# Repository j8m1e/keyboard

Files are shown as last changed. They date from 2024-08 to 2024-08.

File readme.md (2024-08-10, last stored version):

Quefrency
=========

A split 60% staggered keyboard made and sold by Keebio. [More info at Keebio](https://keeb.io).

Keyboard Maintainer: [Bakingpy/nooges](https://github.com/nooges)  
Hardware Supported: Pro Micro  
Hardware Availability: [Keebio](https://keeb.io/)  

Make example for this keyboard (after setting up your build environment):

    make keebio/quefrency/rev1:default

Example of flashing this keyboard:

    make keebio/quefrency/rev1:default:avrdude

Handedness detection is already hardwired onto the PCB, so no need to deal with `EE_HANDS` or flashing .eep files.

See [build environment setup](https://docs.qmk.fm/#/getting_started_build_tools) then the [make instructions](https://docs.qmk.fm/#/getting_started_make_guide) for more information.

A build guide for this keyboard can be found here: [Keebio Build Guides](https://docs.keeb.io)

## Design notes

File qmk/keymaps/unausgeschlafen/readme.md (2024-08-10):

## UNAUSGESCHLAFEN'S QUEFRENCY

This is the keymap that goes with [unausgeschlafen's Quefrency](https://www.reddit.com/r/MechanicalKeyboards/comments/aquefb/my_daily_driver_quefrency/)

If you are using Ardoinos, comment this line in `rules.mk`:
```make
BOOTLOADER = atmel-dfu # comment this line if you use arduinos
```

Although QMK offers one-shot build and flash, I personally build and flash separately (for the Elite C).
I used the QMK default for the Arduino Pro Micros.
However, I do not own them anymore.
Hence, only the instructions for the Elite C are provided.

Build with:
```sh
make keebio/quefrency:unausgeschlafen
```

Flash with:

```sh
sudo dfu-programmer atmega32u4 erase
sudo dfu-programmer atmega32u4 flash keebio_quefrency_rev1_unausgeschlafen.hex
sudo dfu-programmer atmega32u4 reset
```

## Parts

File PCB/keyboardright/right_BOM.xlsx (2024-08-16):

Comment | Designator | Footprint | LCSC Part #（optional）
DIODE-SOD-123 | D1, D2, D3, D4, D6, D7, D8, D9, D10, D11, D12, D13, D14, D15, D16, D17, D18, D19, D20, D21, D22, D23, D24, D25, D26, D27, D28, D30, D31, D32, D33, D34, D35, D36, D37, D38, D39, D40, D41, D42 | SOD-123
MA03-1 | SV1 | MA03-1
KEYSWITCH-PLAIN-MX-1U | U$1, U$2, U$3, U$4, U$6, U$7, U$8, U$9, U$10, U$11, U$12, U$13, U$14, U$15, U$16, U$17, U$18, U$19, U$20, U$21, U$22, U$23, U$24, U$25, U$26, U$27, U$28, U$30, U$31, U$32, U$33, U$34, U$35, U$36, U$37, U$38, U$39, U$40, U$41, U$42 | MX-1U
PROMICRO | U2 | PROMICRO
WS2812B-MINI | RGB1, RGB2, RGB3, RGB4, RGB5, RGB6, RGB7, RGB8, RGB9 | WS2812B-MINI

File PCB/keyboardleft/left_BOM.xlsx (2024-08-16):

Comment | Designator | Footprint | LCSC Part #（optional）
DIODE-SOD-123 | D1, D2, D3, D4, D5, D6, D7, D8, D9, D10, D11, D12, D13, D14, D15, D16, D17, D18, D19, D20, D21, D22, D23, D24, D25, D26, D27, D28, D29, D30, D31, D32, D33, D34, D35, D36, D37, D38, D39, D40 | SOD-123
MA03-1 | SV1 | MA03-1
KEYSWITCH-PLAIN-MX-1U | U$1, U$2, U$3, U$4, U$5, U$6, U$7, U$8, U$9, U$10, U$11, U$12, U$13, U$14, U$15, U$16, U$17, U$18, U$20, U$21, U$22, U$23, U$24, U$25, U$26, U$27, U$28, U$29, U$30, U$31, U$32, U$33, U$34, U$35, U$36, U$37, U$38, U$39, U$40, U$41 | MX-1U
PROMICRO | U1 | PROMICRO
WS2812B-MINI | RGB1, RGB2, RGB3, RGB4, RGB5, RGB6, RGB7, RGB8, RGB9 | WS2812B-MINI

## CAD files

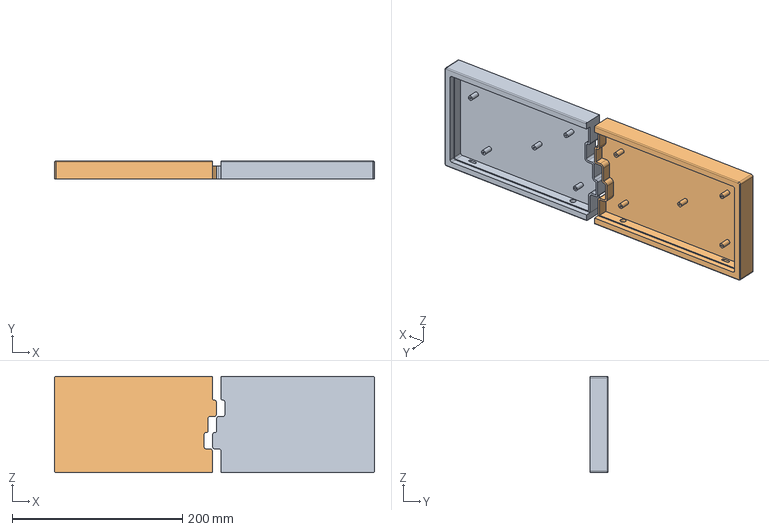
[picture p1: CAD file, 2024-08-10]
design phase/Untitled v0.step
375.7 x 21.0 x 113.3 mm

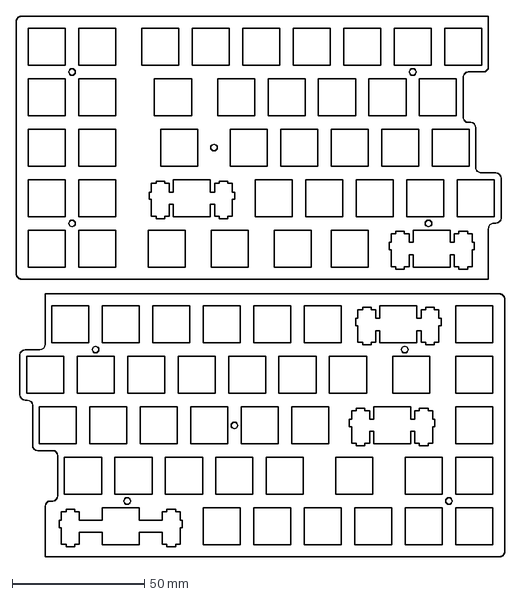
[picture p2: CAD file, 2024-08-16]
PCB/plate.dxf
184.3 x 204.1 mm

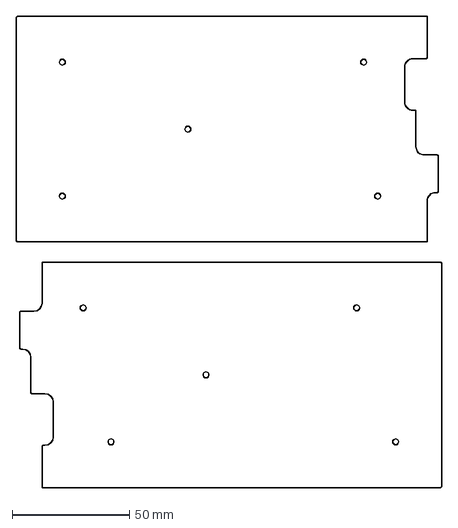
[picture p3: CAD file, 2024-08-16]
PCB/cut.dxf
181.3 x 201.1 mm

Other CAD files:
design phase/Untitled v2.dwg

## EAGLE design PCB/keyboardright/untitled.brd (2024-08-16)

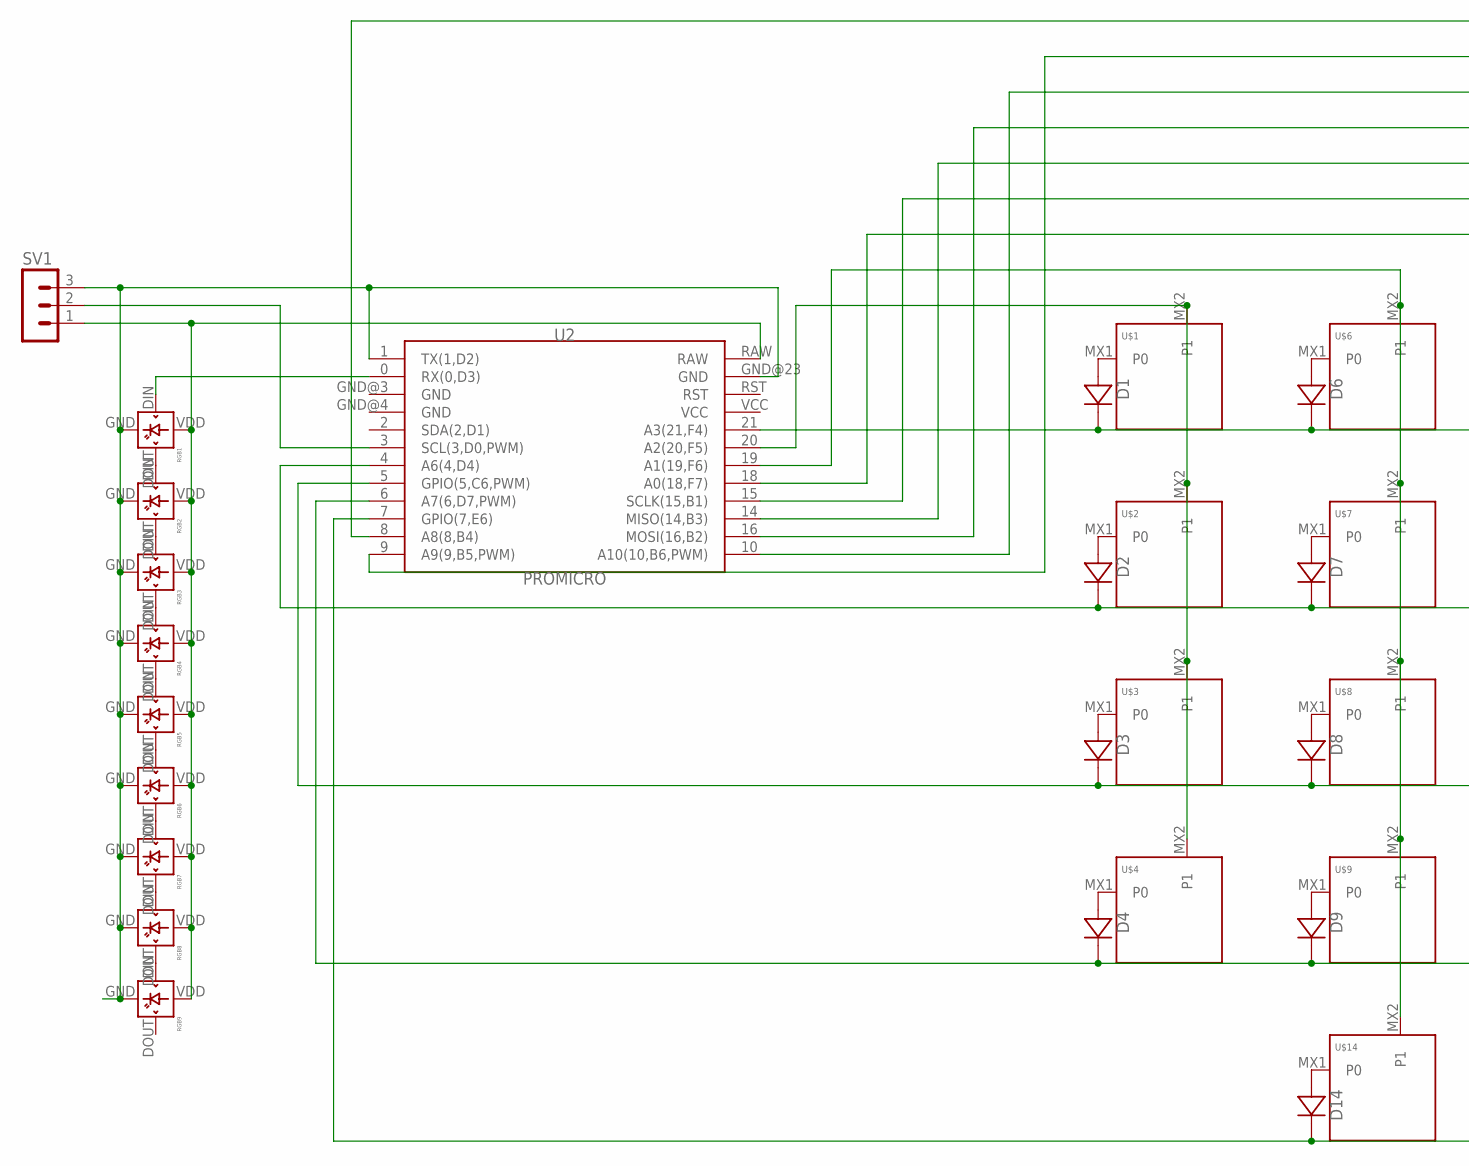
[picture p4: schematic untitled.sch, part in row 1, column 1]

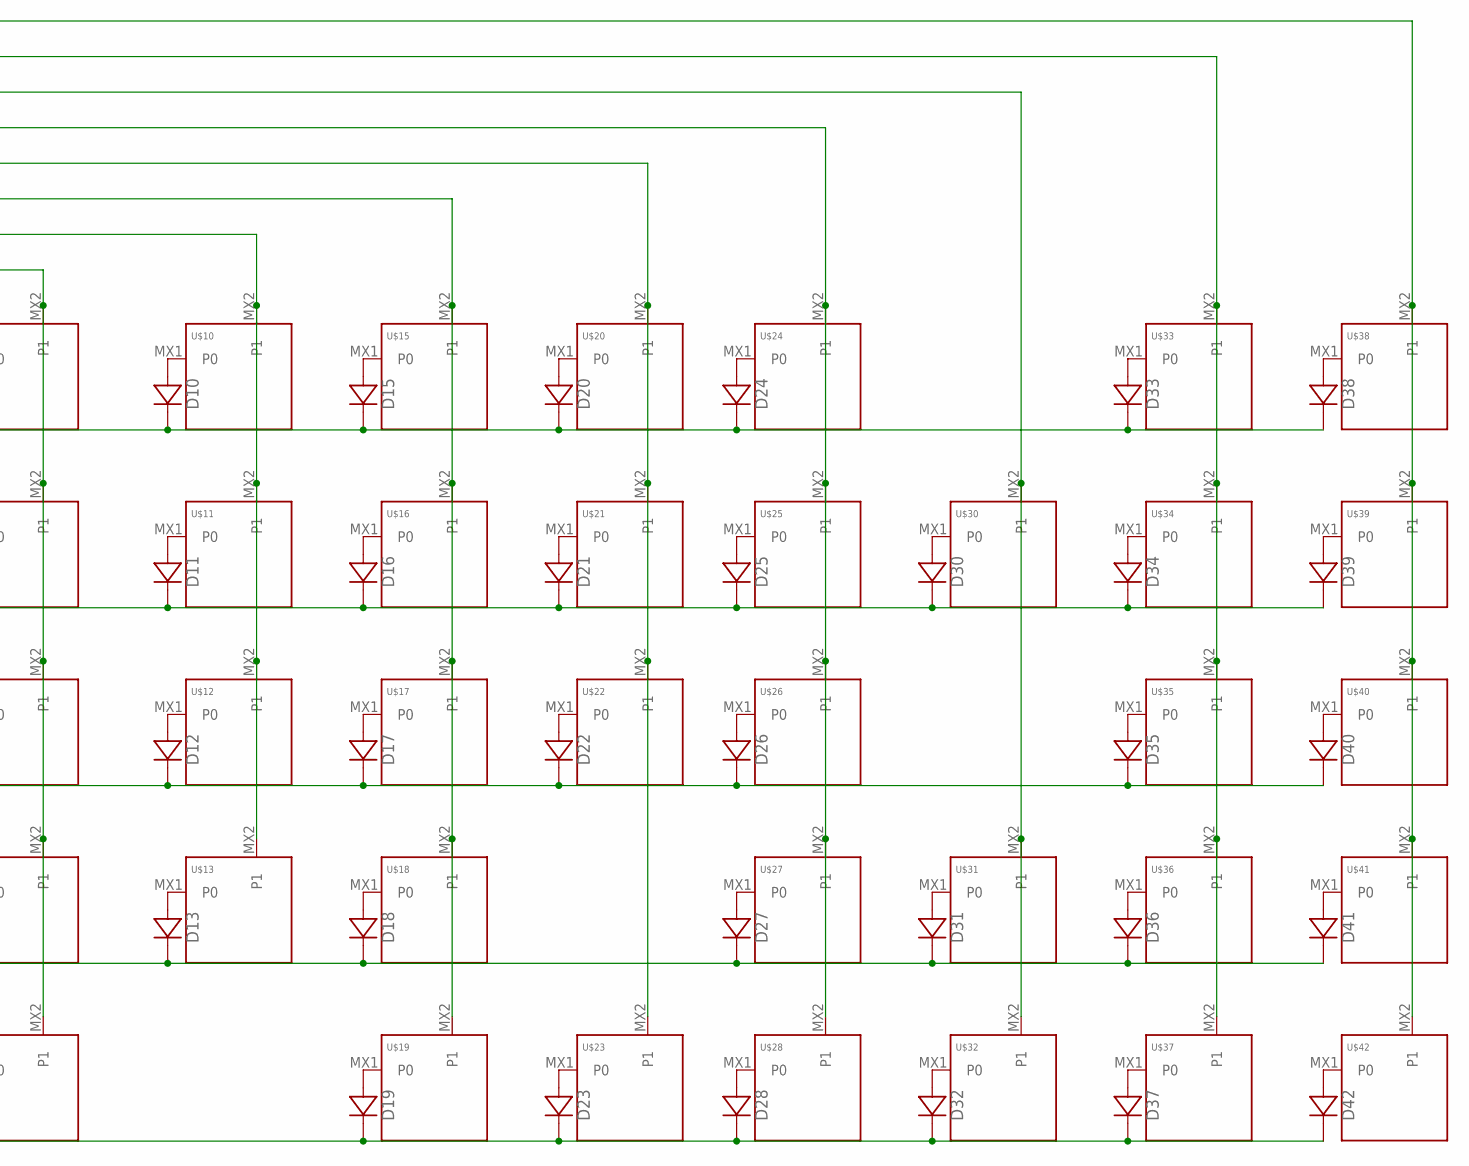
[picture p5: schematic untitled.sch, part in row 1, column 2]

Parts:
D1, D2, D3, D4, D6, D7, D8, D9, D10, D11, D12, D13, D14, D15, D16, D17, D18, D19, D20, D21, D22, D23, D24, D25, D26, D27, D28, D30, D31, D32, D33, D34, D35, D36, D37, D38, D39, D40, D41, D42: DIODE-SOD-123; SOD-123
RGB1, RGB2, RGB3, RGB4, RGB5, RGB6, RGB7, RGB8, RGB9: WS2812B-MINI
SV1: MA03-1
U2: PROMICRO
U$1, U$2, U$3, U$4, U$6, U$7, U$8, U$9, U$10, U$11, U$12, U$13, U$14, U$15, U$16, U$17, U$18, U$19, U$20, U$21, U$22, U$23, U$24, U$25, U$26, U$27, U$28, U$30, U$31, U$32, U$33, U$34, U$35, U$36, U$37, U$38, U$39, U$40, U$41, U$42: KEYSWITCH-PLAIN-MX-1U; MX-1U

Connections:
unnamed: D1.A, U$1.MX1 (P0)
unnamed: D2.A, U$2.MX1 (P0)
unnamed: D3.A, U$3.MX1 (P0)
unnamed: D4.A, U$4.MX1 (P0)
unnamed: RGB1.DOUT, RGB2.DIN
unnamed: D6.A, U$6.MX1 (P0)
unnamed: D7.A, U$7.MX1 (P0)
unnamed: D8.A, U$8.MX1 (P0)
unnamed: D9.A, U$9.MX1 (P0)
unnamed: D10.A, U$10.MX1 (P0)
unnamed: D11.A, U$11.MX1 (P0)
unnamed: D12.A, U$12.MX1 (P0)
unnamed: D13.A, U$13.MX1 (P0)
unnamed: D14.A, U$14.MX1 (P0)
unnamed: D15.A, U$15.MX1 (P0)
unnamed: D16.A, U$16.MX1 (P0)
unnamed: D17.A, U$17.MX1 (P0)
unnamed: D18.A, U$18.MX1 (P0)
unnamed: D19.A, U$19.MX1 (P0)
unnamed: D20.A, U$20.MX1 (P0)
unnamed: D21.A, U$21.MX1 (P0)
unnamed: D22.A, U$22.MX1 (P0)
unnamed: D23.A, U$23.MX1 (P0)
unnamed: D24.A, U$24.MX1 (P0)
unnamed: D25.A, U$25.MX1 (P0)
unnamed: D26.A, U$26.MX1 (P0)
unnamed: D27.A, U$27.MX1 (P0)
unnamed: D28.A, U$28.MX1 (P0)
unnamed: RGB2.DOUT, RGB3.DIN
unnamed: D30.A, U$30.MX1 (P0)
unnamed: D31.A, U$31.MX1 (P0)
unnamed: D32.A, U$32.MX1 (P0)
unnamed: D33.A, U$33.MX1 (P0)
unnamed: D34.A, U$34.MX1 (P0)
unnamed: D35.A, U$35.MX1 (P0)
unnamed: D36.A, U$36.MX1 (P0)
unnamed: D37.A, U$37.MX1 (P0)
unnamed: D38.A, U$38.MX1 (P0)
unnamed: D39.A, U$39.MX1 (P0)
unnamed: D40.A, U$40.MX1 (P0)
unnamed: D41.A, U$41.MX1 (P0)
unnamed: D42.A, U$42.MX1 (P0)
unnamed: U2.20 (A2(20,F5)), U$1.MX2 (P1), U$2.MX2 (P1), U$3.MX2 (P1), U$4.MX2 (P1)
unnamed: U2.19 (A1(19,F6)), U$6.MX2 (P1), U$7.MX2 (P1), U$8.MX2 (P1), U$9.MX2 (P1), U$14.MX2 (P1)
unnamed: U2.18 (A0(18,F7)), U$10.MX2 (P1), U$11.MX2 (P1), U$12.MX2 (P1), U$13.MX2 (P1)
unnamed: U2.15 (SCLK(15,B1)), U$15.MX2 (P1), U$16.MX2 (P1), U$17.MX2 (P1), U$18.MX2 (P1), U$19.MX2 (P1)
unnamed: U2.14 (MISO(14,B3)), U$20.MX2 (P1), U$21.MX2 (P1), U$22.MX2 (P1), U$23.MX2 (P1)
unnamed: U2.16 (MOSI(16,B2)), U$24.MX2 (P1), U$25.MX2 (P1), U$26.MX2 (P1), U$27.MX2 (P1), U$28.MX2 (P1)
unnamed: U2.10 (A10(10,B6,PWM)), U$30.MX2 (P1), U$31.MX2 (P1), U$32.MX2 (P1)
unnamed: U2.9 (A9(9,B5,PWM)), U$33.MX2 (P1), U$34.MX2 (P1), U$35.MX2 (P1), U$36.MX2 (P1), U$37.MX2 (P1)
unnamed: D1.C, D6.C, D10.C, D15.C, D20.C, D24.C, D33.C, D38.C, U2.21 (A3(21,F4))
unnamed: D2.C, D7.C, D11.C, D16.C, D21.C, D25.C, D30.C, D34.C, D39.C, U2.4 (A6(4,D4))
unnamed: D3.C, D8.C, D12.C, D17.C, D22.C, D26.C, D35.C, D40.C, U2.5 (GPIO(5,C6,PWM))
unnamed: D4.C, D9.C, D13.C, D18.C, D27.C, D31.C, D36.C, D41.C, U2.6 (A7(6,D7,PWM))
unnamed: D14.C, D19.C, D23.C, D28.C, D32.C, D37.C, D42.C, U2.7 (GPIO(7,E6))
unnamed: U2.8 (A8(8,B4)), U$38.MX2 (P1), U$39.MX2 (P1), U$40.MX2 (P1), U$41.MX2 (P1), U$42.MX2 (P1)
unnamed: RGB3.DOUT, RGB4.DIN
unnamed: RGB4.DOUT, RGB5.DIN
unnamed: RGB5.DOUT, RGB6.DIN
unnamed: RGB6.DOUT, RGB7.DIN
unnamed: RGB7.DOUT, RGB8.DIN
unnamed: RGB8.DOUT, RGB9.DIN
unnamed: RGB1.VDD, RGB2.VDD, RGB3.VDD, RGB4.VDD, RGB5.VDD, RGB6.VDD, RGB7.VDD, RGB8.VDD, RGB9.VDD, SV1.1, U2.RAW
unnamed: RGB1.GND, RGB2.GND, RGB3.GND, RGB4.GND, RGB5.GND, RGB6.GND, RGB7.GND, RGB8.GND, RGB9.GND, SV1.3, U2.1 (TX(1,D2)), U2.GND@23 (GND)
unnamed: RGB1.DIN, U2.0 (RX(0,D3))
unnamed: SV1.2, U2.3 (SCL(3,D0,PWM))

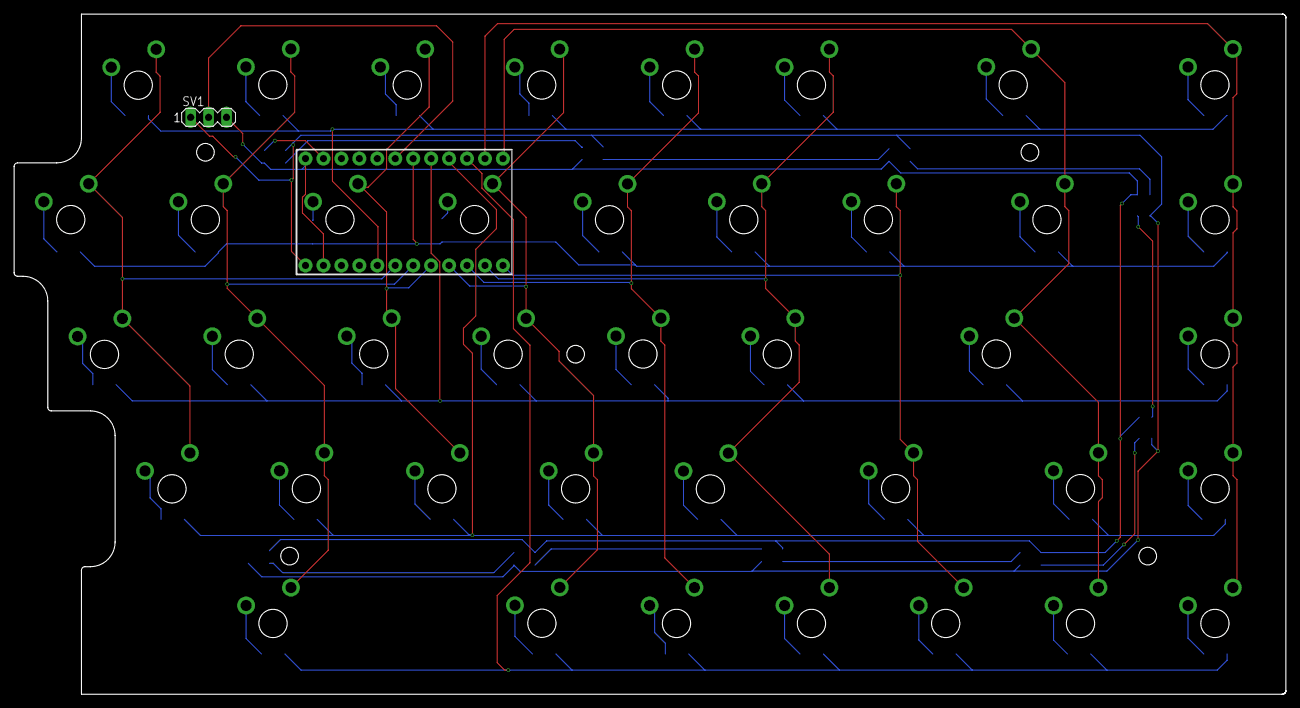
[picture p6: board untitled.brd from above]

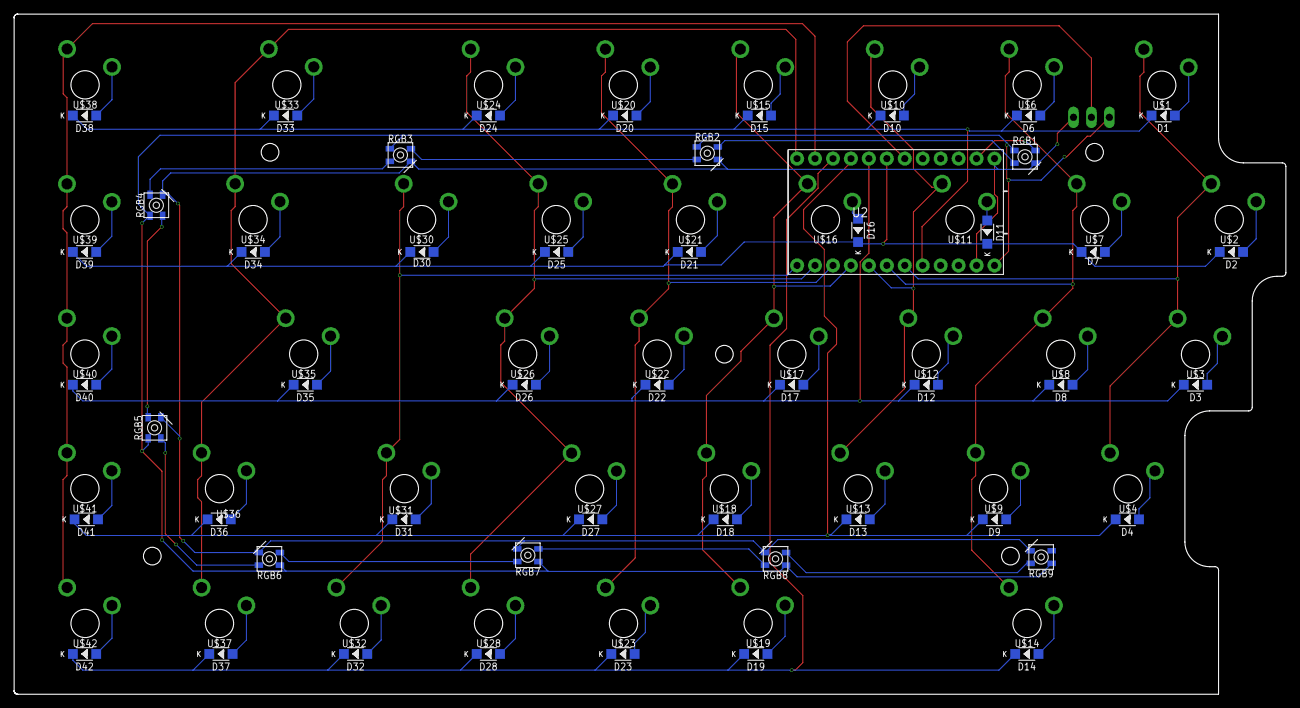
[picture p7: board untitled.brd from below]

Board: 2 copper layers, 180.0 x 96.2 mm, 91 parts (50 on the bottom side), 66 nets.

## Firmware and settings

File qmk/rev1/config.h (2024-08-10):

/*
Copyright 2012 Jun Wako <wakojun@gmail.com>
Copyright 2015 Jack Humbert

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
You should have received a copy of the GNU General Public License
along with this program.  If not, see <http://www.gnu.org/licenses/>.
*/

#pragma once

/* USB Device descriptor parameter */
#define VENDOR_ID       0xCB10
#define PRODUCT_ID      0x1257
#define DEVICE_VER      0x0100
#define MANUFACTURER    Keebio
#define PRODUCT         Quefrency
#define DESCRIPTION     Split 60/65 percent staggered keyboard

/* key matrix size */
// Rows are doubled-up
#define MATRIX_ROWS 10
#define MATRIX_COLS 9

// wiring of each half
#define MATRIX_ROW_PINS { F4, D4, C6, D7, E6}
#define MATRIX_COL_PINS { F5, F6, F7, B1, B3, B2, B6, B5, B4 }
#define MATRIX_ROW_PINS_RIGHT { F4, D4, C6, D7, E6 }
#define MATRIX_COL_PINS_RIGHT { F5, F6, F7, B1, B3, B2, B6, B5, B4 }
#define SPLIT_HAND_PIN D2

/* Set 0 if debouncing isn't needed */
#define DEBOUNCE 5

/* serial.c configuration for split keyboard */
#define SOFT_SERIAL_PIN D0

/* Mechanical locking support. Use KC_LCAP, KC_LNUM or KC_LSCR instead in keymap */
#define LOCKING_SUPPORT_ENABLE
/* Locking resynchronize hack */
#define LOCKING_RESYNC_ENABLE

/* ws2812 RGB LED */
#define RGB_DI_PIN D3
#define RGBLIGHT_ANIMATIONS
#define RGBLED_NUM 20    // Number of LEDs
#define RGBLED_SPLIT { 10, 10 }

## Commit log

2024-08-10 "updated ./design phase/Untitled v0.step"
    [Untitled v0.step]
2024-08-10 "updated ./design phase/Untitled v2.dwg"
    [Untitled v2.dwg]
2024-08-16 "updated ./PCB/plate.dxf"
    [plate.dxf]
2024-08-16 "updated ./PCB/cut.dxf"
    [cut.dxf]
2024-08-16 "updated ./PCB/keyboard-layout.json"
2024-08-16 "updated ./PCB/keyboardleft/untitled.b#3"
2024-08-16 "updated ./PCB/keyboardleft/untitled.b#4"
2024-08-16 "updated ./PCB/keyboardleft/dxfimp.scr"
2024-08-16 "updated ./PCB/keyboardleft/untitled.b#5"
2024-08-16 "updated ./PCB/keyboardleft/untitled.b#2"
2024-08-16 "updated ./PCB/keyboardleft/untitled.brd"
    [untitled.brd]
2024-08-16 "updated ./PCB/keyboardleft/left_CPL.xlsx"
    [left_CPL.xlsx]
2024-08-16 "updated ./PCB/keyboardleft/untitled.s#3"
2024-08-16 "updated ./PCB/keyboardleft/untitled.s#4"
2024-08-16 "updated ./PCB/keyboardleft/untitled.s#5"
2024-08-16 "updated ./PCB/keyboardleft/untitled.s#2"
2024-08-16 "updated ./PCB/keyboardleft/left.zip"
2024-08-16 "updated ./PCB/keyboardleft/untitled.b#7"
2024-08-16 "updated ./PCB/keyboardleft/eagle.epf"
2024-08-16 "updated ./PCB/keyboardleft/untitled.b#1"
2024-08-16 "updated ./PCB/keyboardleft/untitled.b#6"
2024-08-16 "updated ./PCB/keyboardleft/untitled.b#8"
2024-08-16 "updated ./PCB/keyboardleft/left_BOM.xlsx"
    [left_BOM.xlsx]
2024-08-16 "updated ./PCB/keyboardleft/untitled.sch"
    [untitled.sch]
2024-08-16 "updated ./PCB/keyboardleft/untitled.s#1"
2024-08-16 "updated ./PCB/keyboardright/right.zip"
2024-08-16 "updated ./PCB/keyboardright/untitled.b#3"
2024-08-16 "updated ./PCB/keyboardright/untitled.b#4"
2024-08-16 "updated ./PCB/keyboardright/dxfimp.scr"
2024-08-16 "updated ./PCB/keyboardright/untitled.b#5"
2024-08-16 "updated ./PCB/keyboardright/untitled.b#2"
2024-08-16 "updated ./PCB/keyboardright/untitled.brd"
    [untitled.brd]
2024-08-16 "updated ./PCB/keyboardright/right_CPL.xlsx"
    [right_CPL.xlsx]
2024-08-16 "updated ./PCB/keyboardright/untitled.s#3"
2024-08-16 "updated ./PCB/keyboardright/untitled.s#4"
2024-08-16 "updated ./PCB/keyboardright/untitled.s#5"
2024-08-16 "updated ./PCB/keyboardright/untitled.s#2"
2024-08-16 "updated ./PCB/keyboardright/untitled.b#9"
2024-08-16 "updated ./PCB/keyboardright/untitled.b#7"
2024-08-16 "updated ./PCB/keyboardright/eagle.epf"
2024-08-16 "updated ./PCB/keyboardright/untitled.b#1"
2024-08-16 "updated ./PCB/keyboardright/untitled.b#6"
2024-08-16 "updated ./PCB/keyboardright/untitled.b#8"
2024-08-16 "updated ./PCB/keyboardright/right_BOM.xlsx"
    [right_BOM.xlsx]
2024-08-16 "updated ./PCB/keyboardright/untitled.sch"
    [untitled.sch]
2024-08-16 "updated ./PCB/keyboardright/untitled.s#1"
2024-08-16 "updated ./PCB/keyboardright/untitled.s#6"

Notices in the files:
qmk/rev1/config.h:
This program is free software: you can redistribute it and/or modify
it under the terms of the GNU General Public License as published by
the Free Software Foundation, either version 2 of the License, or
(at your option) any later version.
